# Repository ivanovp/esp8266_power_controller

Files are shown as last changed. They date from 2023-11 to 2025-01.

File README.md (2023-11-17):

# esp8266_power_controller
ESP8266 wireless sensor and power controller with P1 (smart meter) input

Videos about the controller (currently only in Hungarian).

Introduction:
https://youtu.be/gTx1W5xfqio

Explaining schematic and PCB:
https://youtu.be/oL1xu2TVqEM

How to configure and upload software:
https://youtu.be/lelAveujqwc

Designing 3D printable case:
https://youtu.be/UKCy7zpQ2Bw

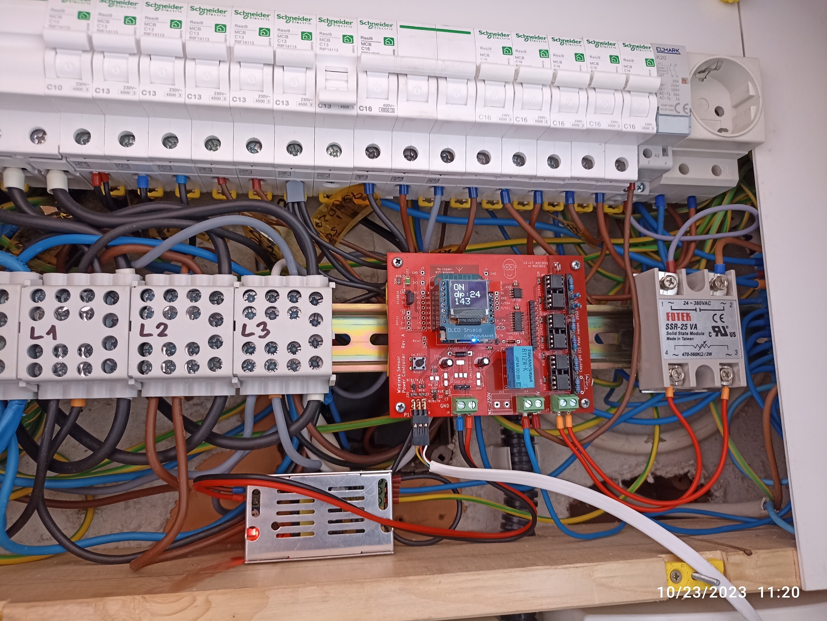
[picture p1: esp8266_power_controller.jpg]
ESP8266 power controller

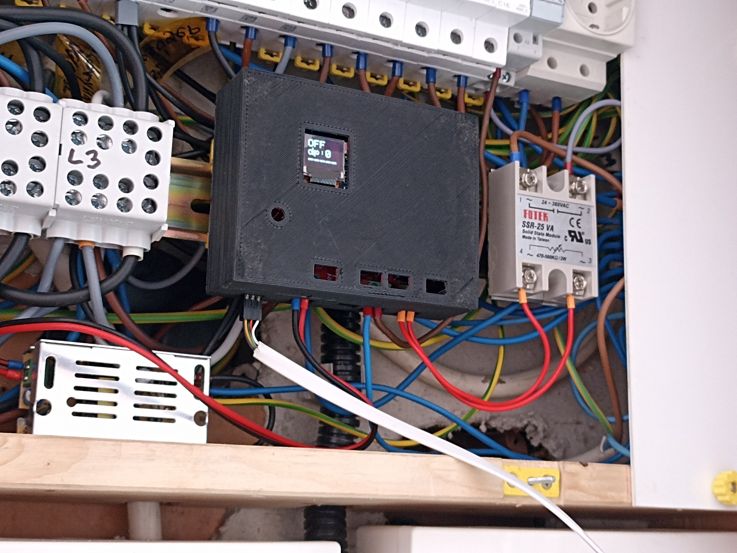
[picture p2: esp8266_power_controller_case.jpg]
Cased ESP8266 power controller

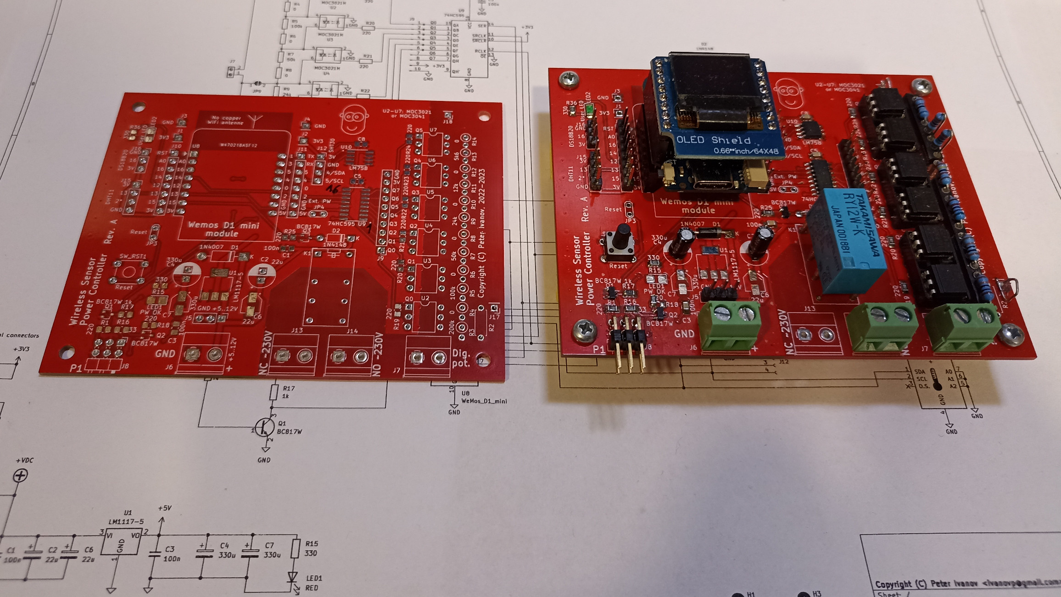
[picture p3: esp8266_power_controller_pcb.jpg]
PCB of ESP8266 power controller


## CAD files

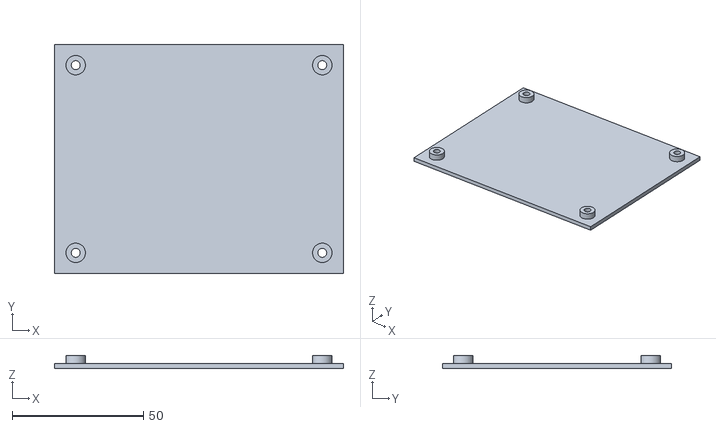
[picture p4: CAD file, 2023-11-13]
3d_printed_case/esp8266_power_controller_bottom.stl
110.1 x 87.3 x 5.00

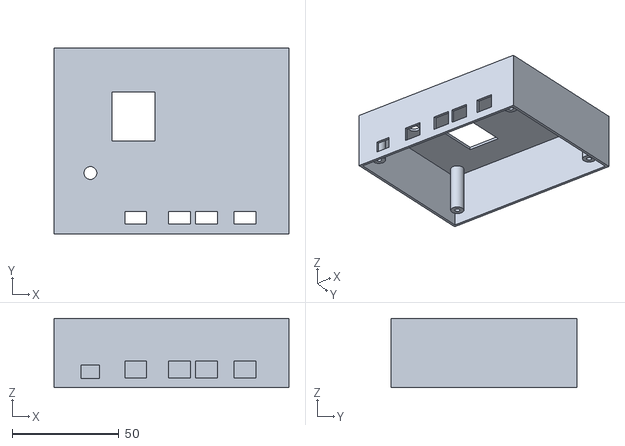
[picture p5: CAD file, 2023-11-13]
3d_printed_case/esp8266_power_controller_top.stl
110.1 x 87.3 x 32.5

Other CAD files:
3d_printed_case/esp8266_power_controller.FCStd

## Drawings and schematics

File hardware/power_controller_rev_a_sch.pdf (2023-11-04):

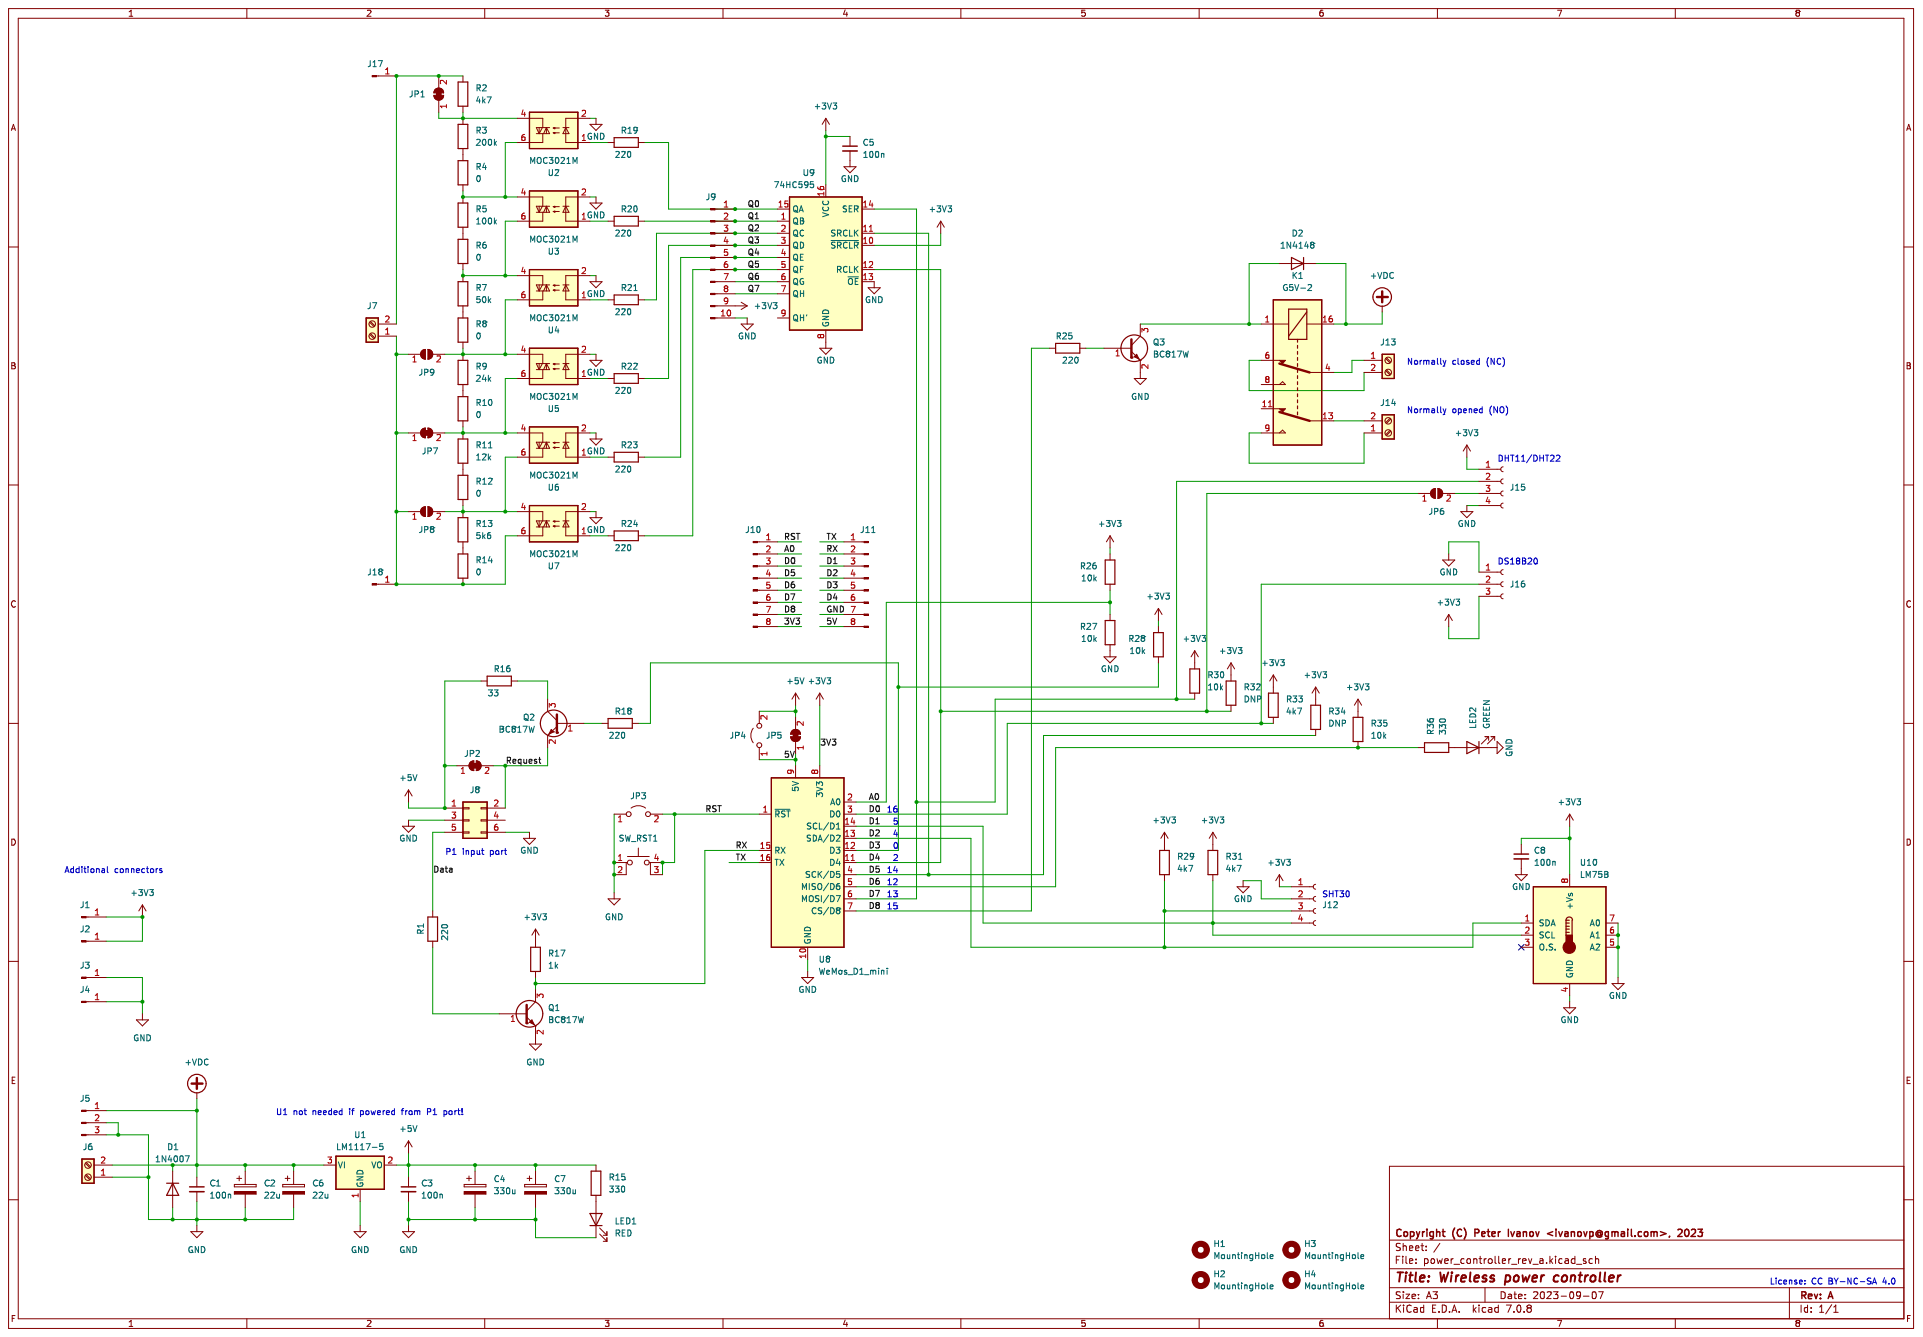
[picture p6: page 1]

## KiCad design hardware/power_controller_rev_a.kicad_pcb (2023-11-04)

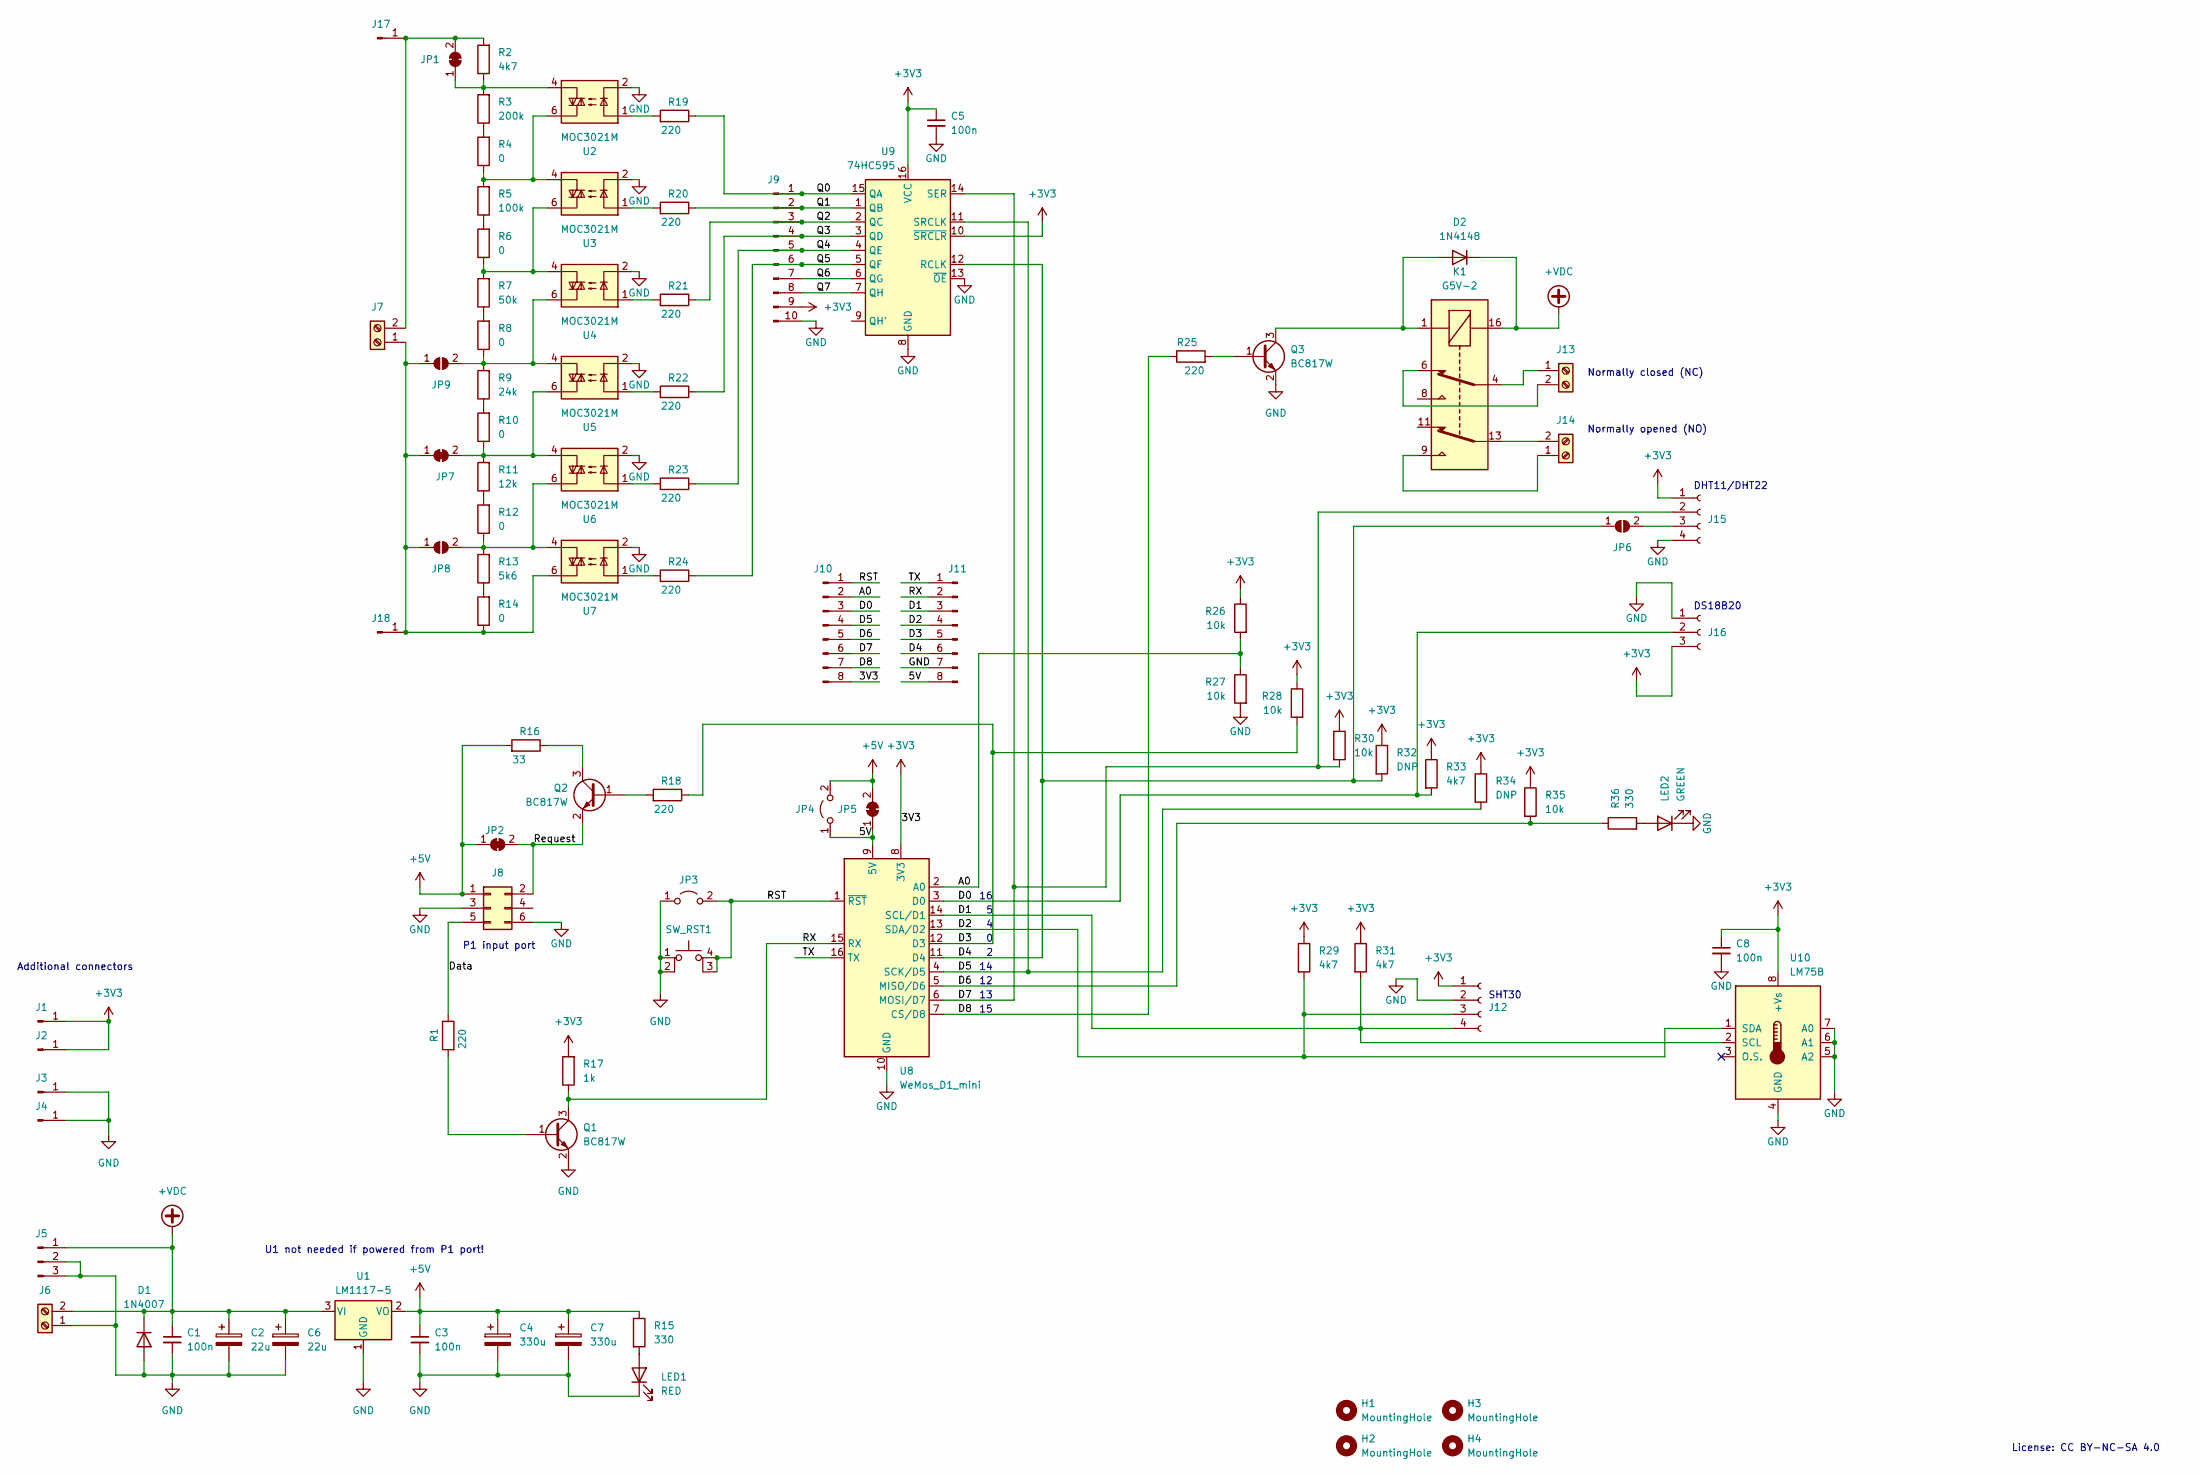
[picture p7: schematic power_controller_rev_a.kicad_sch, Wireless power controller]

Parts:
C1, C3, C5, C8: 100n; C_0805_2012Metric_Pad1.18x1.45mm_HandSolder
C2: 22u; CP_Radial_D6.3mm_P2.50mm
C4: 330u; CP_Radial_D6.3mm_P2.50mm
C6: 22u; CP_Elec_4x3.9
C7: 330u; CP_Elec_4x3.9
D1: 1N4007; D_DO-41_SOD81_P10.16mm_Horizontal
D2: 1N4148; D_DO-35_SOD27_P7.62mm_Horizontal
H1, H2, H3, H4: MountingHole; MountingHole_3.2mm_M3_DIN965
J1, J2, J3, J4, J17, J18: Conn_01x01_Male; PinHeader_1x01_P2.54mm_Vertical
J5: Conn_01x03_Male; PinHeader_1x03_P2.54mm_Vertical
J6, J7, J13, J14: Screw_Terminal_01x02; TerminalBlock_Phoenix_MKDS-1,5-2-5.08_1x02_P5.08mm_Horizont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
J8: Conn_02x03_Odd_Even; PinHeader_2x03_P2.54mm_Horizontal
J9: Conn_01x10_Pin; PinHeader_1x10_P2.54mm_Vertical
J10, J11: Conn_01x08_Pin; PinHeader_1x08_P2.54mm_Vertical
J12, J15: Conn_01x04_Female; PinSocket_1x04_P2.54mm_Vertical
J16: Conn_01x03_Female; PinSocket_1x03_P2.54mm_Vertical
JP1, JP2, JP5, JP7: SolderJumper_2_Bridged; SolderJumper-2_P1.3mm_Bridged_Pad1.0x1.5mm
JP3, JP4: Jumper_2_Open; TestPoint_2Pads_Pitch2.54mm_Drill0.8mm
JP6, JP8, JP9: SolderJumper_2_Open; SolderJumper-2_P1.3mm_Open_Pad1.0x1.5mm
K1: G5V-2; Relay_DPDT_Omron_G5V-2
LED1: RED; LED_0805_1206_3216Metric_Pad1.42x1.75mm_HandSolder
LED2: GREEN; LED_0805_1206_3216Metric_Pad1.42x1.75mm_HandSolder
Q1, Q2, Q3: BC817W; SOT-323_SC-70
R1, R18, R19, R20, R21, R22, R23, R24, R25: 220; R_0805_2012Metric_Pad1.20x1.40mm_HandSolder
R2: 4k7; R_Axial_DIN0207_L6.3mm_D2.5mm_P7.62mm_Horizontal
R3: 200k; R_Axial_DIN0207_L6.3mm_D2.5mm_P2.54mm_Vertical
R4, R6, R8, R10, R12, R14: 0; R_Axial_DIN0207_L6.3mm_D2.5mm_P2.54mm_Vertical
R5: 100k; R_Axial_DIN0207_L6.3mm_D2.5mm_P2.54mm_Vertical
R7: 50k; R_Axial_DIN0207_L6.3mm_D2.5mm_P2.54mm_Vertical
R9: 24k; R_Axial_DIN0207_L6.3mm_D2.5mm_P2.54mm_Vertical
R11: 12k; R_Axial_DIN0207_L6.3mm_D2.5mm_P2.54mm_Vertical
R13: 5k6; R_Axial_DIN0207_L6.3mm_D2.5mm_P2.54mm_Vertical
R15, R36: 330; R_0805_2012Metric_Pad1.20x1.40mm_HandSolder
R16: 33; R_0805_2012Metric_Pad1.20x1.40mm_HandSolder
R17: 1k; R_0805_2012Metric_Pad1.20x1.40mm_HandSolder
R26, R27, R28, R30, R35: 10k; R_0805_2012Metric_Pad1.20x1.40mm_HandSolder
R29, R31, R33: 4k7; R_0805_2012Metric_Pad1.20x1.40mm_HandSolder
R32, R34: DNP; R_0805_2012Metric_Pad1.20x1.40mm_HandSolder
SW_RST1: SW_MEC_5E; SW_TH_Tactile_Omron_B3F-10xx
U1: LM1117-5; SOT-223-3_TabPin2
U2, U3, U4, U5, U6, U7: MOC3021M; DIP-6_W7.62mm
U8: WeMos_D1_mini; WEMOS_D1_mini_light
U9: 74HC595; SOIC-16_3.9x9.9mm_P1.27mm
U10: LM75B; SOIC-8_3.9x4.9mm_P1.27mm

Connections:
+3V3: C5.1, C8.1, J1.1, J2.1, J9.9, J10.8, J12.1, J15.1, J16.3, R17.2, R26.1, R28.1, R29.1, R30.1, R31.1, R32.1, R33.1, R34.1, R35.1, U8.8 (3V3), U9.10 (~SRCLR), U9.16 (VCC), U10.8 (+Vs)
+5V: C3.1, C4.1, C7.1, J8.1, JP2.1 (A), JP4.2 (B), JP5.2 (B), R15.1, R16.2, U1.2 (VO)
+VDC: C1.1, C2.1, C6.1, D1.1 (K), D2.1 (K), J5.1, J6.2, K1.16, U1.3 (VI)
/5V: J11.8, JP4.1 (A), JP5.1 (A), U8.9 (5V)
/A0: J10.2, R26.2, R27.1, U8.2 (A0)
/D0: J10.3, J16.2, R33.2, U8.3 (D0)
/D1: J11.3, J12.4, R31.2, U8.14 (SCL/D1), U10.2 (SCL)
/D2: J11.4, J12.3, R29.2, U8.13 (SDA/D2), U10.1 (SDA)
/D3: J11.5, R18.1, R28.2, U8.12 (D3)
/D4: J11.6, JP6.1 (A), R32.2, U8.11 (D4), U9.12 (RCLK)
/D5: J10.4, R34.2, U8.4 (SCK/D5), U9.11 (SRCLK)
/D6: J10.5, R35.2, R36.1, U8.5 (MISO/D6)
/D7: J10.6, J15.2, R30.2, U8.6 (MOSI/D7), U9.14 (SER)
/D8: J10.7, R25.1, U8.7 (CS/D8)
/Data: J8.5, R1.1
/Q0: J9.1, R19.1, U9.15 (QA)
/Q1: J9.2, R20.1, U9.1 (QB)
/Q2: J9.3, R21.1, U9.2 (QC)
/Q3: J9.4, R22.1, U9.3 (QD)
/Q4: J9.5, R23.1, U9.4 (QE)
/Q5: J9.6, R24.1, U9.5 (QF)
/Q6: J9.7, U9.6 (QG)
/Q7: J9.8, U9.7 (QH)
/RST: J10.1, JP3.2 (B), SW_RST1.3 (K), SW_RST1.4 (A), U8.1 (~RST)
/RX: J11.2, Q1.3 (C), R17.1, U8.15 (RX)
/Request: J8.2, JP2.2 (B), Q2.2 (E)
/TX: J11.1, U8.16 (TX)
GND: C1.2, C2.2, C3.2, C4.2, C5.2, C6.2, C7.2, C8.2, D1.2 (A), J3.1, J4.1, J5.2, J5.3, J6.1, J8.3, J8.6, J9.10, J11.7, J12.2, J15.4, J16.1, JP3.1 (A), LED1.1 (K), LED2.1 (K), Q1.2 (E), Q3.2 (E), R27.2, SW_RST1.1, SW_RST1.2, U1.1 (GND), U2.2, U3.2, U4.2, U5.2, U6.2, U7.2, U8.10 (GND), U9.8 (GND), U9.13 (~OE), U10.4 (GND), U10.5 (A2), U10.6 (A1), U10.7 (A0)
unnamed: D2.2 (A), K1.1, Q3.3 (C)
unnamed: J13.1, K1.4
unnamed: J13.2, K1.6
unnamed: J14.1, K1.9
unnamed: J14.2, K1.13
unnamed: J15.3, JP6.2 (B)
unnamed: J7.2, J17.1, JP1.2 (B), R2.2
unnamed: J7.1, J18.1, JP7.1 (A), JP8.1 (A), JP9.1 (A), R14.1, U7.6
unnamed: JP1.1 (A), R2.1, R3.2, U2.4
unnamed: JP7.2 (B), R10.1, R11.2, U5.6, U6.4
unnamed: JP8.2 (B), R12.1, R13.2, U6.6, U7.4
unnamed: JP9.2 (B), R8.1, R9.2, U4.6, U5.4
unnamed: LED1.2 (A), R15.2
unnamed: LED2.2 (A), R36.2
unnamed: Q1.1 (B), R1.2
unnamed: Q2.1 (B), R18.2
unnamed: Q2.3 (C), R16.1
unnamed: Q3.1 (B), R25.2
unnamed: R3.1, R4.2
unnamed: R4.1, R5.2, U2.6, U3.4
unnamed: R5.1, R6.2
unnamed: R6.1, R7.2, U3.6, U4.4
unnamed: R7.1, R8.2
unnamed: R9.1, R10.2
unnamed: R11.1, R12.2
unnamed: R13.1, R14.2
unnamed: R19.2, U2.1
unnamed: R20.2, U3.1
unnamed: R21.2, U4.1
unnamed: R22.2, U5.1
unnamed: R23.2, U6.1
unnamed: R24.2, U7.1

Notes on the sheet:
P1 input port
License: CC BY-NC-SA 4.0
Normally closed (NC)
DS18B20
U1 not needed if powered from P1 port!
DHT11/DHT22
SHT30
Normally opened (NO)
Additional connectors

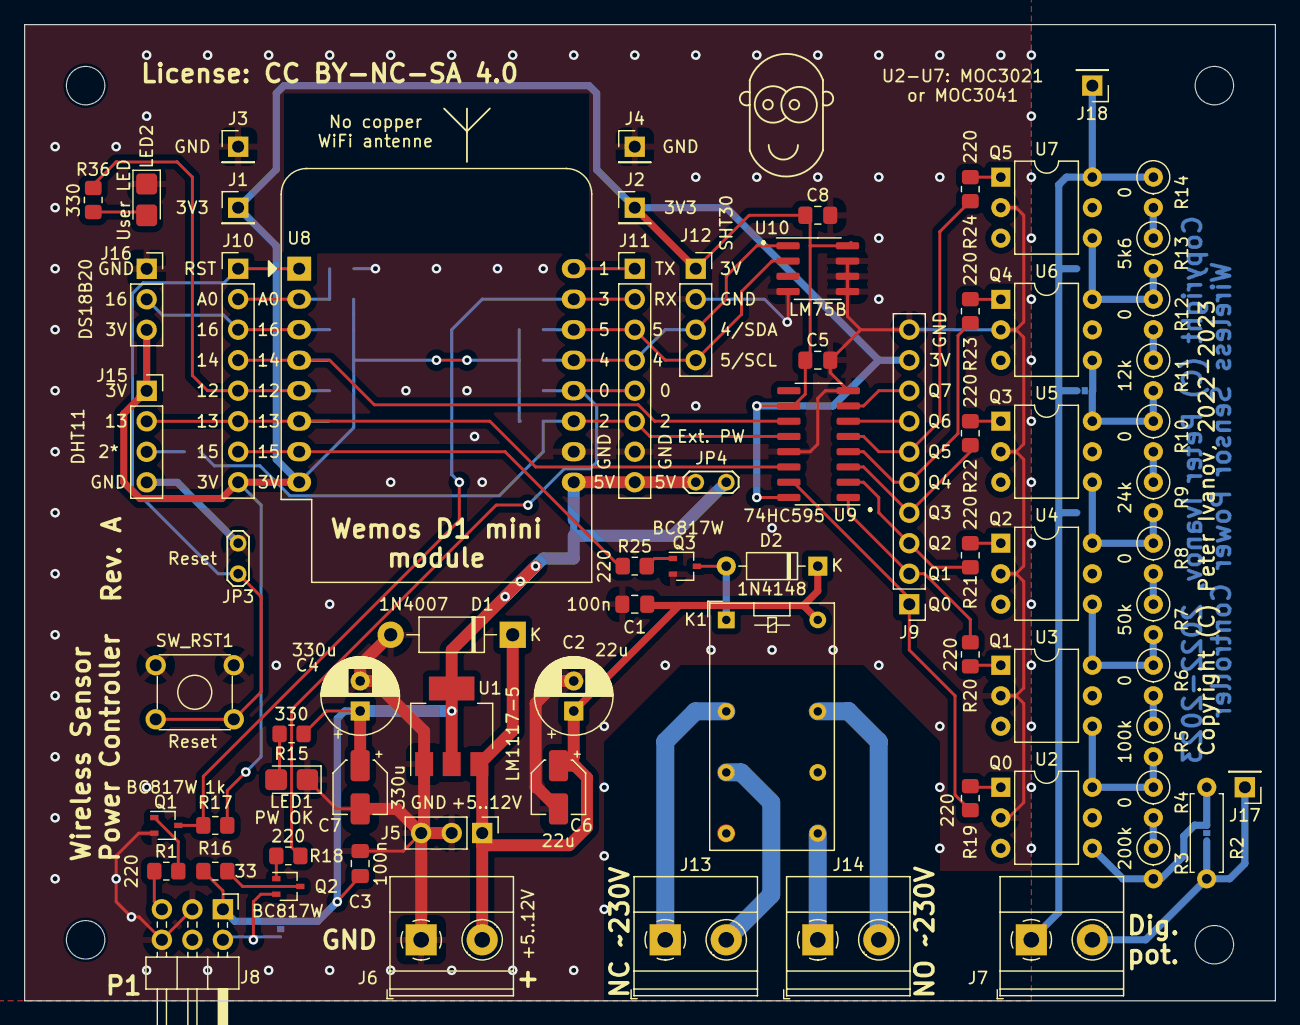
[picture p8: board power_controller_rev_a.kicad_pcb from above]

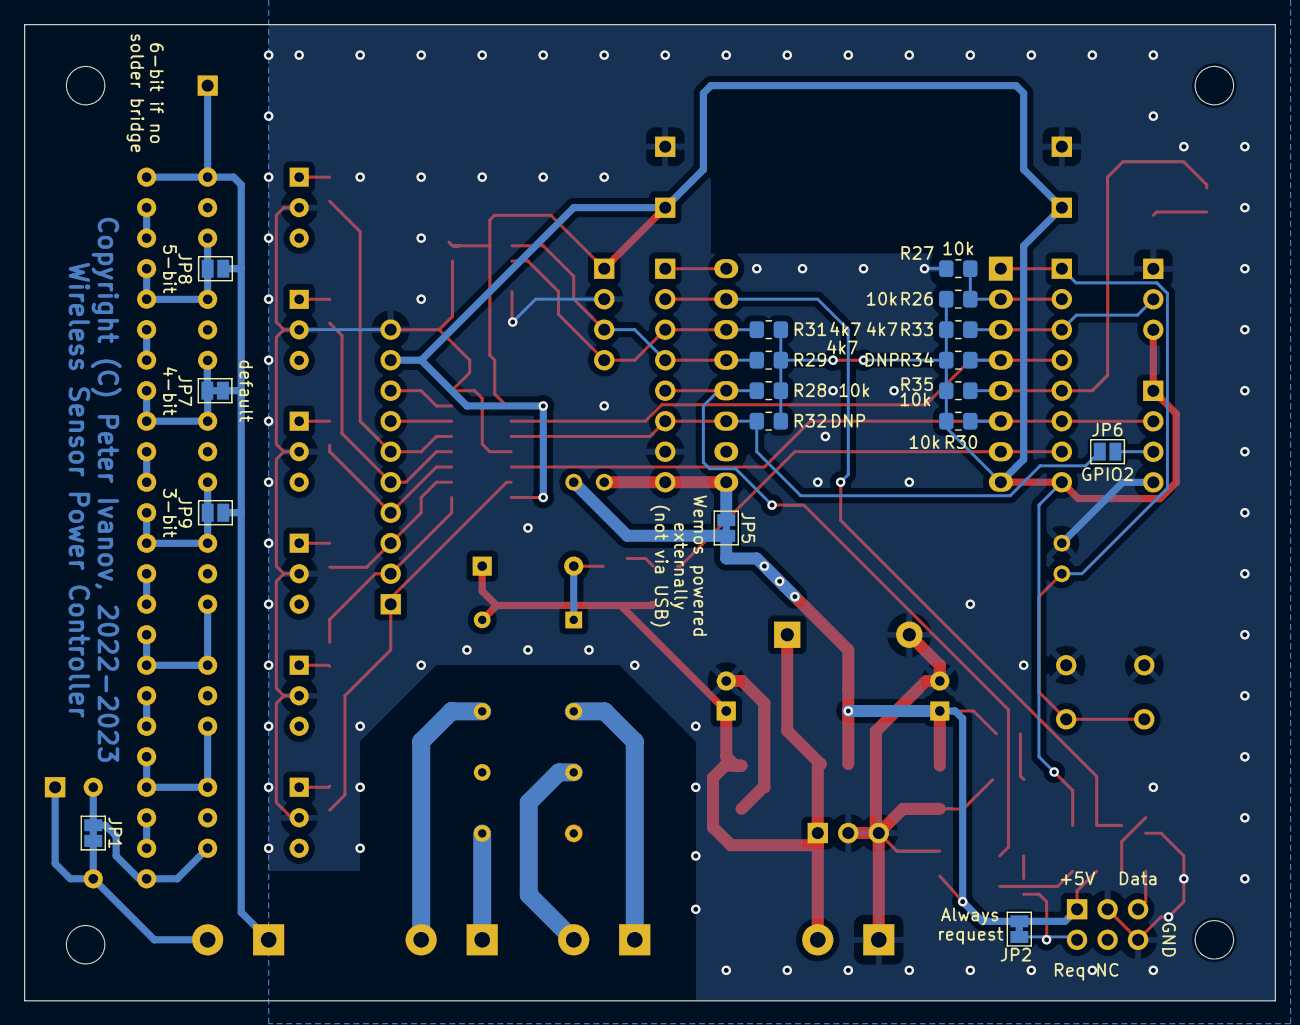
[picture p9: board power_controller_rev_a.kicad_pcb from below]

Board: 2 copper layers, 104.1 x 81.3 mm, 94 parts (17 on the bottom side), 60 nets.

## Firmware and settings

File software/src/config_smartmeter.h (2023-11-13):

/**
 * @file        config_smartmeter.h
 * @brief       Configuration definitions for smart meter
 * @author      Copyright (C) Peter Ivanov, 2011, 2012, 2013, 2014, 2021, 2023
 *
 * Created      2011-01-19 11:48:53
 * Last modify: 2023-11-13 10:06:26 ivanovp {Time-stamp}
 * Licence:     GPL
 */

#ifndef INCLUDE_CONFIG_H_
#define INCLUDE_CONFIG_H_

#define HW_TYPE_ESP01           0   /* ESP8266-01 a.k.a. ESP-01 */
#define HW_TYPE_ESP201          1   /* ESP201 */
#define HW_TYPE_WEMOS_D1_MINI   2   /* Wemos D1 Mini */

#define HW_TYPE                 HW_TYPE_WEMOS_D1_MINI

#define ENABLE_MQTT_CLIENT      0   /* 1: enable MQTT client, 0: disable MQTT client */
#define ENABLE_FIRMWARE_UPDATE  1   /* 1: enable firmware update through HTTP, 0: disable firmware update */
#define ENABLE_RESET            1   /* 1: enable reset through HTTP, 0: disable reset */

/* 1: Enable power metering through serial input */
/*    Standard: DSMR (Dutch Smart Meter Requirements) */
/*    Smart meter's P1 port should be connected to RX pin of ESP8266! */
/* 0: No power metering */
#define ENABLE_POWER_METER                  1
#if ENABLE_POWER_METER
#define ENABLE_POWER_METER_CRC_CHECK        0
#define ENABLE_POWER_METER_DEBUG            1
#define ENABLE_POWER_METER_RELAY            1   /* 1: control relay, 0: no relay */
#define ENABLE_POWER_METER_DIGI_POT         1   /* 1: control digital potmeter, 0: no digital potmeter */
#define ENABLE_POWER_METER_REQUEST          0   /* 1: control request port of P1, 0: no control */

#if ENABLE_POWER_METER_RELAY
#define ENABLE_POWER_METER_RELAY_DEBUG      1
#define ENABLE_POWER_METER_RELAY_TEST       1
#define ENABLE_POWER_METER_LCD              1   /* 1: use 64x48 pixel 0.66 inch OLED shield, 0: no display */
#define POWER_METER_RELAY_PIN               15
#endif
#if ENABLE_POWER_METER_DIGI_POT
#define ENABLE_POWER_METER_DIGI_POT_TEST    0       /* Warning: this might be an endless loop! */
/* 1: Shift register is used to set digital potentiometer */
/* 0: Individual GPIO pins are used to set set digital potentiometer */
#define ENABLE_POWER_METER_DIGI_POT_SR      1

#define POWER_METER_DIGI_POT_BITS           6       /* Number of optotriacs */
#define POWER_METER_DIGI_POT_MIN            0
#define POWER_METER_DIGI_POT_MAX            ((1u << POWER_METER_DIGI_POT_BITS) - 1u)

#if ENABLE_POWER_METER_DIGI_POT_TEST
#define POWER_METER_DIGI_POT_TEST_INPUT_PIN 16
#define ENABLE_POWER_METER_DIGI_POT_TEST_BTN 0  /* Two buttons connected to analog input (A0) */
#endif

#if ENABLE_POWER_METER_DIGI_POT_SR
/* RCLK pin of 74HC595 shift register */
#define POWER_METER_DIGI_POT_SR_RCLK_PIN    2   /* GPIO2 */
#else
#define POWER_METER_DIGI_POT_PIN0           16
#define POWER_METER_DIGI_POT_PIN1           14
#define POWER_METER_DIGI_POT_PIN2           12
#define POWER_METER_DIGI_POT_PIN3           13
#endif

#if ENABLE_POWER_METER_REQUEST
/* Periodic LOW/HIGH setting is currently disabled. Reason: */
/* My smart meter (Sanxing SX631) is sending OBIS data in every 10 seconds, */
/* and it cannot be forced to send it in every 2 or 5 seconds by pulling */
/* request pin low then high. */
#define POWER_METER_REQUEST_PERIOD_MS       0   /* 0: periodic LOW/HIGH disabled */
#define POWER_METER_REQUEST_WIDTH_MS        0   /* 0: periodic LOW/HIGH disabled */
#define POWER_METER_REQUEST_PIN             0   /* GPIO0 */
#endif

/* Maximum current consumption in Ampers */
/* Note: this is the maximum supported current by software */
/* Controlled heater elements' maximum current is defined in digipot.txt! */
#define POWER_METER_DIGI_POT_MAX_CURRENT_A  25
#endif
#endif

#define ENABLE_TM1637_DISP      0

#define ENABLE_SHT3X            0   /* Temperature and humidity sensor (I2C) */
#define ENABLE_BMP280           0   /* Pressure and temperature sensor (I2C) */
#define ENABLE_DS18B20          0   /* Temperature sensor (Dallas 1-wire) */
#define ENABLE_LM75             1   /* Temperature sensor (I2C) */
#define ENABLE_DHT              0   /* DHT11/DHT22 temperature and humidity sensor (special 1-wire) */
#define ENABLE_I2C              0

/* Do not change the following values! */
#define SENSOR_NONE             0
#define SENSOR_SHT3X            1
#define SENSOR_BMP280           2
#define SENSOR_DS18B20          3
#define SENSOR_LM75             4
#define SENSOR_DHT              5

/* Select which sensor provides the pressure, temperature, humidity values */
#define PRESSURE_SENSOR         SENSOR_NONE
#define TEMPERATURE_SENSOR      SENSOR_LM75
#define HUMIDITY_SENSOR         SENSOR_NONE

// name of the server. You reach it using http://sensor<MAC>
#define DEFAULT_HOSTNAME "sensor"

// TODO define time zone in file!
// local time zone definition (Berlin, Belgrade, Budapest, Oslo, Paris, etc.)
#define TIMEZONE "CET-1CEST,M3.5.0,M10.5.0/3"

#define MQTT_CONNECT_RETRY_SEC                  5
#define MQTT_PUBLISH_INTERVAL_SEC               10
#define HTTP_SERVER_PORT                        80
#define DEFAULT_HOMEPAGE_REFRESH_INTERVAL_SEC   60

#define SHT31_ADDRESS                   0x44
#define DS18B20_PIN                     14 /* GPIO14 */
#define DHTPIN                          13 /* GPIO13 */
#define DHTTYPE                         DHT22     // DHT22=DHT 22 (AM2302), DHT21=DHT 21 (AM2301)

/* Blue LED on Wemos D1 mini */
/* Note: RCLK of 74HC595 and Blue LED use the same GPIO on Wireless Sensor Controller Board Rev A! */
#if POWER_METER_DIGI_POT_SR_RCLK_PIN != 2
#define LED_PIN                         2   /* GPIO2 */
#define LED_INVERTED                    1
#endif
/* Green LED (LED2) on red power controller board */
#define LED2_PIN                        12   /* GPIO12 */
#define LED2_INVERTED                   0

#if ENABLE_TM1637_DISP
#define TM1637_CLK                      13
#define TM1637_DIO                      12
#endif

#if ENABLE_POWER_METER
#define MAX_OBIS_CODE_NUM               50
#define POWER_METER_CONFIG_FILE         "obis2mqtt.txt"

#if ENABLE_POWER_METER_RELAY
#define POWER_METER_RELAY_CONFIG_FILE   "relay.txt"
#if ENABLE_POWER_METER_DIGI_POT
#define POWER_METER_DIGI_POT_CONFIG_FILE "digipot.txt"
#endif
#endif /* ENABLE_POWER_METER_RELAY */
#endif /* ENABLE_POWER_METER */

#define COMMENT_CHAR                    ';'

#define BOARD_RESET_TIME_MS             1000

#endif /* INCLUDE_CONFIG_H_ */

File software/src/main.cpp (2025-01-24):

/**
 * @file        main.cpp
 * @brief       Main program
 * @author      Copyright (C) Peter Ivanov, 2011, 2012, 2013, 2014, 2021, 2023
 *
 * Created      2011-01-19 11:48:53
 * Last modify: 2023-10-12 11:28:21 ivanovp {Time-stamp}
 * Licence:     GPL
 */

#include <Arduino.h>
#include <ESP8266WebServer.h>
#include <ESP8266mDNS.h>
// Example firmware upload via curl:
// curl -F "image=@.pio/build/esp07/firmware.bin" http://smartmeter.home/update.htm
#include <ESP8266HTTPUpdateServer.h>
#include "Adafruit_SHT31.h"
#include "Adafruit_BMP280.h"
#include "DallasTemperature.h"        /* DS18B20 */
#include "Temperature_LM75_Derived.h" /* LM75 and derivatives (TMP100, TMP102) */
#include "Adafruit_Sensor.h"
#include "DHT.h"
#include "DHT_U.h"
#include "PubSubClient.h" /* MQTT */
#include "TM1637Display.h"

#include "main.h"
#include "common.h"
#include "config.h"
#include "secrets.h" // add WLAN Credentials in here.
#include "power_meter.h"

#include <FS.h>       // File System for Web Server Files
#include <LittleFS.h> // This file system is used.

#define PLAUSIBLE_TEMPERATURE_THRESHOLD_C (-99.0f)
#define MEASUREMENT_RETRY_DELAY_MS (100)
#define MEASUREMENT_RETRY_COUNT (3)

const char *ssid = STASSID;
const char *passPhrase = STAPSK;

#if ENABLE_SHT3X
Adafruit_SHT31 sht;
float temperature_sht3x;
float humidity_sht3x;
#endif
#if ENABLE_BMP280
Adafruit_BMP280 bmp;
float pressure_bmp280;
float temperature_bmp280;
#endif
#if ENABLE_DS18B20
OneWire one_wire(DS18B20_PIN);
DallasTemperature dallas_temperature(&one_wire);
float temperature_ds18b20;
#endif
#if ENABLE_LM75
Generic_LM75 lm75;
float temperature_lm75;
#endif
#if ENABLE_DHT
DHT_Unified dht(DHTPIN, DHTTYPE);
float temperature_dht;
float humidity_dht;
#endif

#if TEMPERATURE_SENSOR != SENSOR_NONE
float temperature;
#endif
#if HUMIDITY_SENSOR != SENSOR_NONE
float humidity;
#endif
#if PRESSURE_SENSOR != SENSOR_NONE
float pressure;
/* Calibration values from pressurecalib.txt */
float pressureOffset = 0.0f; /* First line in pressurecalib.txt */
float pressureFactor = 1.0f; /* Second line in pressurecalib.txt */
#endif
#if ENABLE_POWER_METER
#define TITLE_STR "Power measurement"
#else
#if TEMPERATURE_SENSOR != SENSOR_NONE && HUMIDITY_SENSOR != SENSOR_NONE && PRESSURE_SENSOR != SENSOR_NONE
#define TITLE_STR "Pressure, temperature and humidity measurement"
#endif
#if TEMPERATURE_SENSOR != SENSOR_NONE && HUMIDITY_SENSOR != SENSOR_NONE && PRESSURE_SENSOR == SENSOR_NONE
#define TITLE_STR "Temperature and humidity measurement"
#endif
#if TEMPERATURE_SENSOR == SENSOR_NONE && HUMIDITY_SENSOR != SENSOR_NONE && PRESSURE_SENSOR != SENSOR_NONE
#define TITLE_STR "Pressure and humidity measurement"
#endif
#if TEMPERATURE_SENSOR != SENSOR_NONE && HUMIDITY_SENSOR == SENSOR_NONE && PRESSURE_SENSOR != SENSOR_NONE
#define TITLE_STR "Pressure and temperature measurement"
#endif
#if TEMPERATURE_SENSOR != SENSOR_NONE && HUMIDITY_SENSOR == SENSOR_NONE && PRESSURE_SENSOR == SENSOR_NONE
#define TITLE_STR "Temperature measurement"
#endif
#if TEMPERATURE_SENSOR == SENSOR_NONE && HUMIDITY_SENSOR != SENSOR_NONE && PRESSURE_SENSOR == SENSOR_NONE
#define TITLE_STR "Humidity measurement"
#endif
#if TEMPERATURE_SENSOR == SENSOR_NONE && HUMIDITY_SENSOR == SENSOR_NONE && PRESSURE_SENSOR != SENSOR_NONE
#define TITLE_STR "Pressure measurement"
#endif
#if TEMPERATURE_SENSOR == SENSOR_NONE && HUMIDITY_SENSOR == SENSOR_NONE && PRESSURE_SENSOR == SENSOR_NONE
#error No sensors defined!
#endif
#endif

// need a WebServer for http access on port 80.
ESP8266WebServer httpServer(HTTP_SERVER_PORT);
#if ENABLE_FIRMWARE_UPDATE
ESP8266HTTPUpdateServer httpUpdater;
#endif

String hostname;

WiFiClient wifiClient;
#if ENABLE_MQTT_CLIENT
PubSubClient mqttClient(wifiClient);

uint32_t mqtt_connect_start_time = 0;
uint32_t mqtt_publish_start_time = 0;
uint32_t mqtt_publish_interval_sec = MQTT_PUBLISH_INTERVAL_SEC;
String mqttTopicPrefix;
#if TEMPERATURE_SENSOR != SENSOR_NONE
String mqttTopicTemperature;
#endif
#if HUMIDITY_SENSOR != SENSOR_NONE
String mqttTopicHumidity;
#endif
#if PRESSURE_SENSOR != SENSOR_NONE
String mqttTopicPressure;
#endif
#endif /* ENABLE_MQTT_CLIENT */

uint32_t homepage_refresh_interval_sec = DEFAULT_HOMEPAGE_REFRESH_INTERVAL_SEC; /* First line homepage_refresh_interval.txt */
#if ENABLE_RESET
bool_t board_reset = FALSE;
uint32_t board_reset_timestamp_ms = 0;
#endif

#if ENABLE_TM1637_DISP
TM1637Display display(TM1637_CLK, TM1637_DIO);
#endif

// The text of builtin files are in this header file
#include "builtinfiles.h"

void setLed(bool_t on)
{
#if LED_PIN != 0
    if (
#if LED_INVERTED
        !on // Inverse logic on Wemos D1 Mini
#else
        on
#endif
    )
    {
        digitalWrite(LED_PIN, HIGH);
    }
    else
    {
        digitalWrite(LED_PIN, LOW);
    }
#endif
}

void setLed2(bool_t on)
{
#if LED2_PIN != 0
    if (
#if LED2_INVERTED
        !on
#else
        on
#endif
    )
    {
        digitalWrite(LED2_PIN, HIGH);
    }
    else
    {
        digitalWrite(LED2_PIN, LOW);
    }
#endif
}

/*
 * Read given line of a file and return.

 * @param[in] filename      File to open and read.
 * @param[in] lineIdx       Line index (nth) to read.
 * @param[in] commentChar   Ignore this character and all data after this character
 *
 * @return nth line of file.
 */
String readStringFromFile(const String &filename, uint16_t lineIdx, uint8_t commentChar, bool_t removeTrailingSpaces)
{
    String content;
    uint16_t idx;
    int commentCharIdx;

    File file = LittleFS.open(filename, "r");
    if (file)
    {
        /* Read nth - 1 line from file and discard */
        idx = lineIdx;
        while (idx-- > 0)
        {
            file.readStringUntil('\n');
        }
        if (file.available())
        {
            content = file.readStringUntil('\n');
            if (commentChar != 0)
            {
                commentCharIdx = content.indexOf(commentChar);
                /* Check if comment character is in the string */
                if (commentCharIdx != -1)
                {
                    /* Remove comment character and evrything after that*/
                    content.remove(commentCharIdx);
                }
            }

            if (removeTrailingSpaces)
            {
                idx = content.length() - 1;
                /* Remove trailing spaces */
                while (content[idx] == ' ' || content[idx] == '\t')
                {
                    content.remove(idx);
                    idx--;
                }
            }
        }
        TRACE("Line #%i from file '%s': '%s'\n", lineIdx, filename.c_str(), content.c_str());
    }
    else
    {
        ERROR("Failed to open file %s for reading\n", filename.c_str());
    }

    return content;
}

void measure_internal()
{
    uint8_t retry_cnt;

#if ENABLE_SHT3X
    retry_cnt = MEASUREMENT_RETRY_COUNT;
    do
    {
        temperature_sht3x = sht.readTemperature();
        humidity_sht3x = sht.readHumidity();
        TRACE("Temperature_SHT3X: %.2f\n", temperature_sht3x + 0.005f);
        TRACE("Humidity_SHT3X: %.2f\n", humidity_sht3x + 0.005f);
#if TEMPERATURE_SENSOR == SENSOR_SHT3X
        temperature = temperature_sht3x;
#endif
#if HUMIDITY_SENSOR == SENSOR_SHT3X
        humidity = humidity_sht3x;
#endif
        if (temperature_sht3x < PLAUSIBLE_TEMPERATURE_THRESHOLD_C)
        {
            delay(MEASUREMENT_RETRY_DELAY_MS);
        }
    } while (temperature_sht3x < PLAUSIBLE_TEMPERATURE_THRESHOLD_C && retry_cnt--);
#endif

#if ENABLE_BMP280
    retry_cnt = MEASUREMENT_RETRY_COUNT;
    do
    {
        pressure_bmp280 = bmp.readPressure() / 100.0f;
        pressure_bmp280 += pressureOffset;
        pressure_bmp280 *= pressureFactor;
        temperature_bmp280 = bmp.readTemperature();
        TRACE("Temperature_BMP280: %.2f\n", temperature_bmp280 + 0.005f);
        TRACE("Pressure_BMP280: %.2f\n", pressure_bmp280 + 0.005f);
#if PRESSURE_SENSOR == SENSOR_BMP280
        pressure = pressure_bmp280;
#endif
        if (temperature_bmp280 < PLAUSIBLE_TEMPERATURE_THRESHOLD_C)
        {
            delay(MEASUREMENT_RETRY_DELAY_MS);
        }
    } while (temperature_bmp280 < PLAUSIBLE_TEMPERATURE_THRESHOLD_C && retry_cnt--);
#endif

#if ENABLE_DS18B20
    retry_cnt = MEASUREMENT_RETRY_COUNT;
    do
    {
        dallas_temperature.requestTemperatures();
        temperature_ds18b20 = dallas_temperature.getTempCByIndex(0);
        TRACE("Temperature_DS18B20: %.2f\n", temperature_ds18b20 + 0.005f);
#if TEMPERATURE_SENSOR == SENSOR_DS18B20
        temperature = temperature_ds18b20;
#endif
        if (temperature_ds18b20 < PLAUSIBLE_TEMPERATURE_THRESHOLD_C)
        {
            delay(MEASUREMENT_RETRY_DELAY_MS);
        }
    } while (temperature_ds18b20 < PLAUSIBLE_TEMPERATURE_THRESHOLD_C && retry_cnt--);
#endif

#if ENABLE_LM75
    retry_cnt = MEASUREMENT_RETRY_COUNT;
    do
    {
        temperature_lm75 = lm75.readTemperatureC();
        TRACE("Temperature_LM75: %.2f\n", temperature_lm75 + 0.005f);
#if TEMPERATURE_SENSOR == SENSOR_LM75
        temperature = temperature_lm75;
#endif
        if (temperature_lm75 < PLAUSIBLE_TEMPERATURE_THRESHOLD_C)
        {
            delay(MEASUREMENT_RETRY_DELAY_MS);
        }
    } while (temperature_lm75 < PLAUSIBLE_TEMPERATURE_THRESHOLD_C && retry_cnt--);
#endif

#if ENABLE_DHT
    retry_cnt = MEASUREMENT_RETRY_COUNT;
    do
    {
        sensors_event_t event;
        dht.temperature().getEvent(&event);
        if (isnan(event.temperature))
        {
            temperature_dht = -100.0f;
        }
        else
        {
            temperature_dht = event.temperature;
        }
        TRACE("Temperature_DHT: %.2f\n", temperature_dht + 0.005f);
#if TEMPERATURE_SENSOR == SENSOR_DHT
        temperature = temperature_dht;
#endif
        dht.humidity().getEvent(&event);
        if (isnan(event.relative_humidity))
        {
            humidity_dht = -100.0f;
        }
        else
        {
            humidity_dht = event.relative_humidity;
        }
        TRACE("Humidity_DHT: %.2f\n", humidity_dht + 0.005f);
#if HUMIDITY_SENSOR == SENSOR_DHT
        humidity = humidity_dht;
#endif
        if (temperature_dht < PLAUSIBLE_TEMPERATURE_THRESHOLD_C)
        {
            delay(MEASUREMENT_RETRY_DELAY_MS);
        }
    } while (temperature_dht < PLAUSIBLE_TEMPERATURE_THRESHOLD_C && retry_cnt--);
#endif

#if TEMPERATURE_SENSOR != SENSOR_NONE
    TRACE("Temperature: %.2f C\n", temperature + 0.005f);
#endif
#if HUMIDITY_SENSOR != SENSOR_NONE
    TRACE("Humidity: %.2f %%\n", humidity + 0.005f);
#endif
#if PRESSURE_SENSOR != SENSOR_NONE
    TRACE("Pressure: %.2f hPa\n", pressure + 0.005f);
#endif
}

void measure()
{
    setLed(TRUE);
    measure_internal();
    setLed(FALSE);
#if ENABLE_TM1637_DISP
#if 1
    uint8_t segments[4];
    if (temperature >= 0 && temperature < 100)
    {
        /* Between 0 and 100 Celsius */
        segments[0] = display.encodeDigit((int)(temperature / 10) % 10);
        segments[1] = display.encodeDigit(((int)temperature) % 10);
        segments[2] = SEG_E; /* no decimal point, so use segment E as decimap point*/
        segments[3] = display.encodeDigit((int)((temperature + 0.05f) * 10) % 10);
    }
    else if (temperature >= 100)
    {
        /* Greater than 100 Celsius */
        segments[0] = 0;
        segments[1] = display.encodeDigit((int)(temperature / 100) % 10);
        segments[2] = display.encodeDigit((int)(temperature / 10) % 10);
        segments[3] = display.encodeDigit(((int)temperature) % 10);
    }
    else
    {
        /* Negative temperature */
        segments[0] = SEG_G;
        segments[1] = display.encodeDigit((int)(-temperature / 100) % 10);
        segments[2] = display.encodeDigit((int)(-temperature / 10) % 10);
        segments[3] = display.encodeDigit(((int)-temperature) % 10);
    }
    display.setSegments(segments);
#else
    display.showNumberDec((int)temperature);
#endif
#endif
}

// ===== Simple functions used to answer simple GET requests =====

#if 0
// This function is called when the WebServer was requested without giving a filename.
// This will redirect to the file index.htm when it is existing otherwise to the built-in upload.htm page
void handleRedirect()
{
    TRACE("Redirect...\n");
    String url = "/index.htm";

    if (!LittleFS.exists(url))
    {
        url = "/upload.htm";
    }

    httpServer.sendHeader("Location", url, true);
    httpServer.send(302);
}
#endif

/*
 * It generates page /index.htm and /
 */
void handleIndex()
{
    String buf;

    measure();

    buf += "<!DOCTYPE html PUBLIC \"-//W3C//DTD XHTML 1.0 Strict//EN\"";
    buf += "\"http://www.w3.org/TR/xhtml1/DTD/xhtml1-strict.dtd\">";
    buf += "<html xmlns=\"http://www.w3.org/1999/xhtml\" lang=\"en\" xml:lang=\"en\">";
    buf += "<head><meta http-equiv=\"content-type\" content=\"text/html; charset=utf-8\"/>";
    if (homepage_refresh_interval_sec > 0)
    {
        buf += "<meta http-equiv=\"refresh\" content=\"" + String(homepage_refresh_interval_sec) + "\"/>"; // automatically reload in 60 seconds
    }
    buf += "<meta name=\"mobile-web-app-capable\" content=\"yes\">";
#if ENABLE_POWER_METER
    buf += "<meta name=\"viewport\" content=\"user-scalable=no, width=device-width, initial-scale=1.0, maximum-scale=1.0\"/>";
#else
    buf += "<meta name=\"viewport\" content=\"user-scalable=no, width=device-width, initial-scale=1.2, maximum-scale=1.2\"/>";
#endif
    buf += "<title>" TITLE_STR "</title>";
    buf += "<link Content-Type=\"text/css\" href=\"/style.css\" rel=\"stylesheet\" />";
    buf += "</head><body>";
    buf += "<h1>" TITLE_STR "</h1>";
    buf += "<p>";
#if ENABLE_POWER_METER
    uint16_t idx;
    String data;

    if (obis_data_length)
    {
        /* OBIS data received from smart meter */
        buf += "<table><tr>";
        if (obis2mqtt_valid)
        {
            /* There is obis2mqtt conversion table (from configuration file) */
            if (obis2mqtt_global_flags & OBIS2MQTT_GLOBAL_FLAG_ALWAYS_SHOW_OBIS_CODES)
            {
                buf += "<th>OBIS code (register)</th>";
            }
            buf += "<th>Description</th><th>Value</th></tr>";
            /* There is obis2mqtt.txt configuration */
            obis_data_t *p_obis_data = NULL;

            for (idx = 0; idx < obis2mqtt_length && idx < MAX_OBIS_CODE_NUM; idx++)
            {
                p_obis_data = find_obis_data(obis2mqtt[idx].obis_code);
                if (p_obis_data && !(obis2mqtt[idx].flags & OBIS2MQTT_FLAG_DO_NOT_SHOW_INDEX))
                {
                    buf += "<tr>";
                    data = p_obis_data->data_with_unit;
                    /* OBIS code found, we can translate OBIS code to a human readable string */
                    if (obis2mqtt_global_flags & OBIS2MQTT_GLOBAL_FLAG_ALWAYS_SHOW_OBIS_CODES)
                    {
                        /* Show OBIS code */
                        buf += "<td>" + p_obis_data->obis_code + "</td>";
                    }
                    /* Show data with pre-defined human readable string */
                    buf += "<td>" + obis2mqtt[idx].human_readable_string + "</td><td>" + data + "</td>";
                    buf += "</tr>";
                }
            }
        }
        else
        {
            /* No obis2mqtt.txt configuration, show raw OBIS code and data */
            buf += "<th>OBIS code</th><th>Value</th></tr>";
            for (idx = 0; idx < obis_data_length && idx < MAX_OBIS_CODE_NUM; idx++)
            {
                buf += "<tr><td>" + obis_data[idx].obis_code + "</td><td>" + obis_data[idx].data_with_unit + "</td></tr>";
            }
        }
        buf += "</table>";
        buf += "<br>OBIS data age: " + String((millis() - obis_data_timestamp_ms) / 1000) + " second<br>";
    }
    else
    {
        buf += "No OBIS data received yet.<br>";
    }
#if ENABLE_POWER_METER_RELAY
    buf += "<br>Relay is ";
    if (relay_is_on)
    {
        buf += "ON";
    }
    else
    {
        buf += "OFF";
    }
    buf += "<br>";
#if ENABLE_POWER_METER_DIGI_POT
    buf += "Digital potmeter: " + String(power_meter_digi_pot_value);
    buf += " (max. " + String(POWER_METER_DIGI_POT_MAX) + ")<br>";
#endif
    buf += "<br>";
#endif
#endif
#if TEMPERATURE_SENSOR != SENSOR_NONE
    buf += "Temperature: " + String(temperature + 0.005f, 2) + " &deg;C<br>";
#endif
#if HUMIDITY_SENSOR != SENSOR_NONE
    buf += "Humidity: " + String(humidity + 0.005f, 2) + " %<br>";
#endif
#if PRESSURE_SENSOR != SENSOR_NONE
    buf += "Pressure: " + String(pressure + 0.005f, 2) + " hPa<br>";
#endif
    buf += "<br>Uptime: " + String(millis() / 1000) + " seconds<br>";
    buf += "</p>";
    buf += "<p><a href=\"/admin.htm\">Admin</a></p>";
    buf += "<p>Copyright (C) Peter Ivanov &lt;<a href=\"mailto:ivanovp@gmail.com\">ivanovp@gmail.com</a>&gt;, 2023.<br>";
    buf += "</p></body></html>";

    httpServer.sendHeader("Cache-Control", "no-cache");
    httpServer.send(200, "text/html; charset=utf-8", buf);
}

#if ENABLE_RESET
/*
 * It resets the board.
 */
void handleReset()
{
    String buf;

    buf += "<!DOCTYPE html PUBLIC \"-//W3C//DTD XHTML 1.0 Strict//EN\"";
    buf += "\"http://www.w3.org/TR/xhtml1/DTD/xhtml1-strict.dtd\">";
    buf += "<html xmlns=\"http://www.w3.org/1999/xhtml\" lang=\"en\" xml:lang=\"en\">";
    buf += "<head><meta http-equiv=\"content-type\" content=\"text/html; charset=utf-8\"/>";
    buf += "<meta http-equiv=\"refresh\" content=\"" + String(BOARD_RESET_TIME_MS / 1000 + 5) + "; URL=index.htm\" />";
    buf += "<meta name=\"mobile-web-app-capable\" content=\"yes\">";
    buf += "<title>" TITLE_STR "</title>";
    buf += "<link Content-Type=\"text/css\" href=\"/style.css\" rel=\"stylesheet\" />";
    buf += "</head><body>";
    buf += "<p>Board will be resetted in " + String(BOARD_RESET_TIME_MS) + " milliseconds...";
    buf += "</p></body></html>";

    httpServer.sendHeader("Cache-Control", "no-cache");
    httpServer.send(200, "text/html; charset=utf-8", buf);

    board_reset = TRUE;
    board_reset_timestamp_ms = millis();
}
#endif

// This function is called when the WebServer was requested to list all existing files in the filesystem.
// a JSON array with file information is returned.
void handleListFiles()
{
    Dir dir = LittleFS.openDir("/");
    String result;

    result += "[\n";
    while (dir.next())
    {
        if (result.length() > 4)
        {
            result += ",";
        }
        result += "  {";
        result += " \"name\": \"" + dir.fileName() + "\", ";
        result += " \"size\": " + String(dir.fileSize()) + ", ";
        result += " \"time\": " + String(dir.fileTime());
        result += " }\n";
        // jc.addProperty("size", dir.fileSize());
    } // while
    result += "]";
    httpServer.sendHeader("Cache-Control", "no-cache");
    httpServer.send(200, "text/javascript; charset=utf-8", result);
}

// This function is called when the sysInfo service was requested.
void handleSysInfo()
{
    String result;

    FSInfo fs_info;
    LittleFS.info(fs_info);

    result += "{\n";
    result += "  \"firmwareVersionMajor\": " TOSTR(VERSION_MAJOR) "\n";
    result += "  , \"firmwareVersionMinor\": " TOSTR(VERSION_MINOR) "\n";
    result += "  , \"firmwareVersionRevision\": " TOSTR(VERSION_REVISION) "\n";
    result += "  , \"hostName\": \"" + String(WiFi.getHostname()) + "\"\n";
    result += "  , \"macAddress\": \"" + WiFi.macAddress() + "\"\n";
    result += "  , \"ipAddress\": \"" + WiFi.localIP().toString() + "\"\n";
    result += "  , \"ipMask\": \"" + WiFi.subnetMask().toString() + "\"\n";
    result += "  , \"dnsIp\": \"" + WiFi.dnsIP().toString() + "\"\n";
    result += "  , \"flashSize\": " + String(ESP.getFlashChipSize()) + "\n";
    result += "  , \"freeHeap\": " + String(ESP.getFreeHeap()) + "\n";
    result += "  , \"fsTotalBytes\": " + String(fs_info.totalBytes) + "\n";
    result += "  , \"fsUsedBytes\": " + String(fs_info.usedBytes) + "\n";
    result += "  , \"uptime_ms\": " + String(millis()) + "\n";
    result += "  , \"pressureSensorType\": " TOSTR(PRESSURE_SENSOR) "\n";
    result += "  , \"temperatureSensorType\": " TOSTR(TEMPERATURE_SENSOR) "\n";
    result += "  , \"humiditySensorType\": " TOSTR(HUMIDITY_SENSOR) "\n";
#if ENABLE_SHT3X
    result += "  , \"SHT3X\": 1\n";
#endif
#if ENABLE_BMP280
    result += "  , \"BMP280\": 1\n";
#endif
#if ENABLE_DS18B20
    result += "  , \"DS18B20\": 1\n";
#endif
#if ENABLE_LM75
    result += "  , \"LM75\": 1\n";
#endif
#if ENABLE_DHT
    result += "  , \"DHT\": 1\n";
#endif
#if ENABLE_POWER_METER
    result += "  , \"powerMeter\": 1\n";
#if ENABLE_POWER_METER_CRC_CHECK
    result += "  , \"powerMeterCrcCheck\": 1\n";
#endif
#if ENABLE_POWER_METER_RELAY
    result += "  , \"powerMeterRelay\": 1\n";
#endif
#if ENABLE_POWER_METER_RELAY_TEST
    result += "  , \"powerMeterRelayTest\": 1\n";
#endif
#if ENABLE_POWER_METER_DIGI_POT
    result += "  , \"powerMeterDigiPot\": 1\n";
    result += "  , \"powerMeterDigiPotBits\": " TOSTR(POWER_METER_DIGI_POT_BITS) "\n";
#if ENABLE_POWER_METER_DIGI_POT_TEST
    result += "  , \"powerMeterDigiPotTest\": 1\n";
#endif
#endif
#if ENABLE_POWER_METER_LCD
    result += "  , \"powerMeterRelayLcd\": 1\n";
#endif
#endif
    result += "  , \"compileDate\": \"" __DATE__ "\"\n";
    result += "  , \"compileTime\": \"" __TIME__ "\"\n";
    result += "}";
    httpServer.sendHeader("Cache-Control", "no-cache");
    httpServer.send(200, "text/javascript; charset=utf-8", result);
} // handleSysInfo()
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
void loop(void)
{
#if ENABLE_RESET
    uint32_t now;
#endif

    httpServer.handleClient();
#if ENABLE_FIRMWARE_UPDATE
    MDNS.update();
#endif
#if ENABLE_MQTT_CLIENT
    mqtt_task();
#endif
#if ENABLE_POWER_METER
    power_meter_task();
#endif
#if ENABLE_RESET
    now = millis();
    if (board_reset && now >= BOARD_RESET_TIME_MS && now - BOARD_RESET_TIME_MS >= board_reset_timestamp_ms)
    {
        TRACE("Restarting...");
        ESP.restart();
    }
#endif
}

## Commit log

2023-11-04 Initial commit of hardware.
    [power_controller_rev_a.kicad_pcb, power_controller_rev_a.kicad_sch]
2023-11-06 Images of power controller were added.
2023-11-07 MQTT client can be disabled in config.h. Maximum current can be defined in digipot.txt.
2023-11-07 Typo was fixed in digipot.txt. Comment was added.
    [config_smartmeter.h]
2023-11-13 Comments were added and fixed in configuration. Test buttons were disabled.
    [config_smartmeter.h]
2023-11-13 Case was added: FreeCAD design and STL files.
    [esp8266_power_controller.FCStd, esp8266_power_controller_bottom.stl, esp8266_power_controller_top.stl]
2023-11-17 Picture of 3D printed case was added. Another youtube link was added to Readme.
2023-11-17 Picture of 3D printed case was added to Readme.
2023-11-19 Compiling error was eliminated which occurred when ENABLE_POWER_METER=0.
    [power_meter.cpp]

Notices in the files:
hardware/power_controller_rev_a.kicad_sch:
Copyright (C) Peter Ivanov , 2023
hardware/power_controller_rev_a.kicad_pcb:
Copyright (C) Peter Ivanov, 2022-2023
